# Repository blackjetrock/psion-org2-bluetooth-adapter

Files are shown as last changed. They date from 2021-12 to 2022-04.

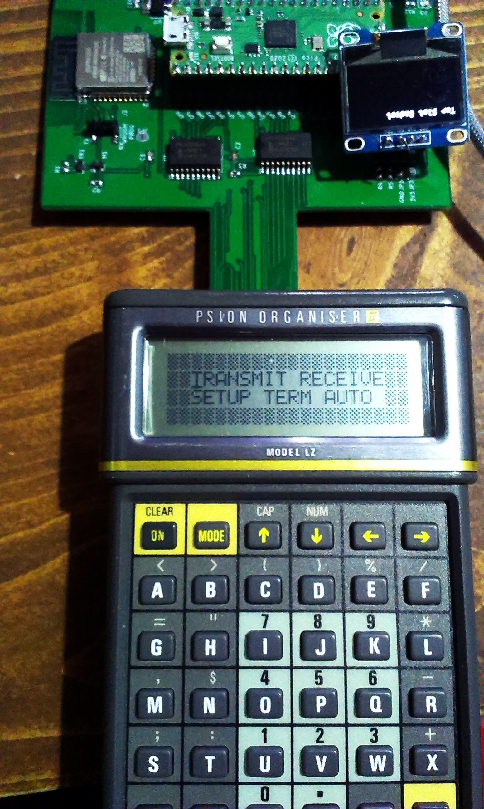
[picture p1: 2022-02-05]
photos/IMAG1584.jpg

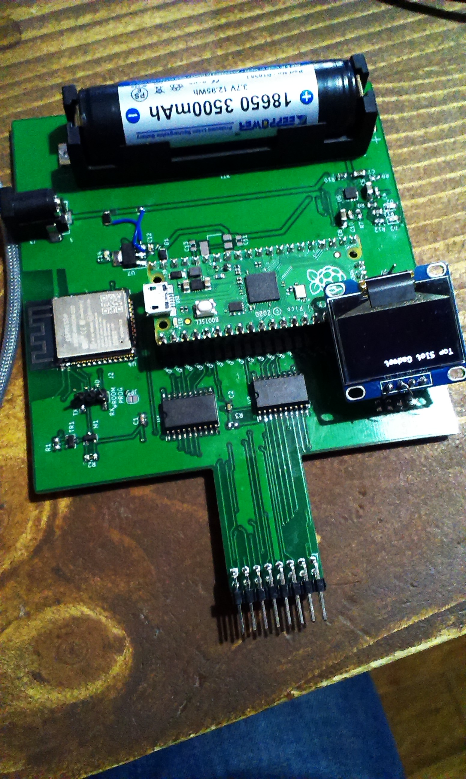
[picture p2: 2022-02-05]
photos/IMAG1581.jpg

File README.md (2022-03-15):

# psion-org2-bluetooth-adapter
Bluetooth adapter for Psion Organiser II

NOTE:Very much a prototype that needs modifications to run properly.

An adapter for the Psion Organiser II which has the Comms Link ROM in a Pico. hardware for bluetooth is a WROOM module.
The unit plugs in to the top slot of a PSion Organiser II and allows Bluetooth traffic to be passed on to the organiser.
The original comms link code runs on the Pico as it emulates a datapack ROM.

V1.0
----

Prototype PCB that is not designed to fit in a case.
Power from 1 cell Li-ion. Regulator should take input from jack and drop it to 5V. Battery charger/power path outputs 5.5V down to battery voltage. 
Pico takes output from regulator (5.5V to VBAT) and buck boosts to 3V3. 3V3 output from Pico drives external circuitry up to 300mA.
If running WROOM off 3V3 is too much then use 3V3 regulator off VREG.

V1.1
----

Movd charging circuit to the ETA6002 as soldering the BQxxx was tricky. This circuit doesn't really work as the datasheet has little data so I'm not sure about a lot of aspects of this chip. The code has had to be rewritten to not use interrupts. Instead of using one of the hardware UARTs and a PIO UART the code now uses two UARTS made fom PIOs. This doesn't use interrupts and works a lot better.
Master mode works on th elatest code and I have had two organisers communicating, on ein master mode and pone in slave using the TERM menu. Seems OK. The TRANSMIT menu option messes something up though, although it looks like the data is sent.
Turn off handshaking in the SETUP menu.
9600,n,8,1 is the Psion setting that is needed.

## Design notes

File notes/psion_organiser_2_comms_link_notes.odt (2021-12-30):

Psion organiser 2 Comms Link Notes

The 6303 has a serial IO capability on th efollowing pins:

Port2 Pin 3: Input (RX)

Port2 Pin 4: Output (TX)

The rate of transmission is set up in registers as required.

The 74HC244 places signals on the SDx bus when OE is asserted. If OE is not asserted then datapack Rom accesses can be made as normal.

OE on the 74HC244 is driven from the NAND of SOE and the inversion of SS.

So when SS is high and OE is high, the 74HC244 is enabled and pins 3 and 4 of the SDx bus are connected to the MAX232 driver.

The Rom is disabled at this time as SOE is high so there is no contention.

When the driver is not attached to the SD bus the RX and TX lineson the 25 way connector appear to be undefined. There are no pull ups or downs on the schematic.

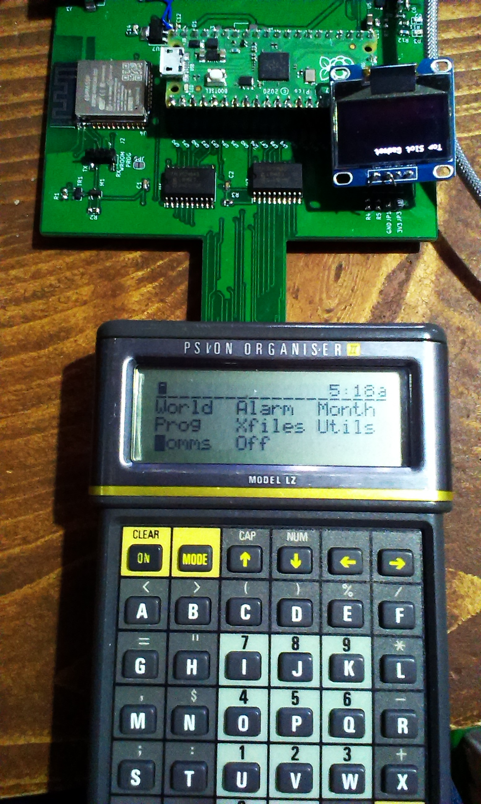
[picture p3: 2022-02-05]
photos/IMAG1583.jpg

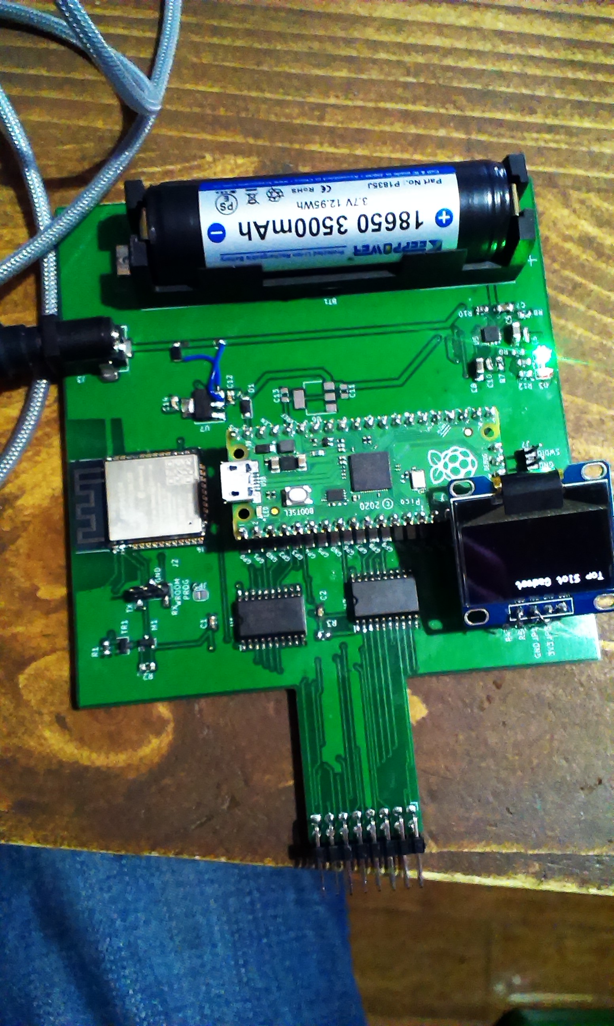
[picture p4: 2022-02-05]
photos/IMAG1582.jpg

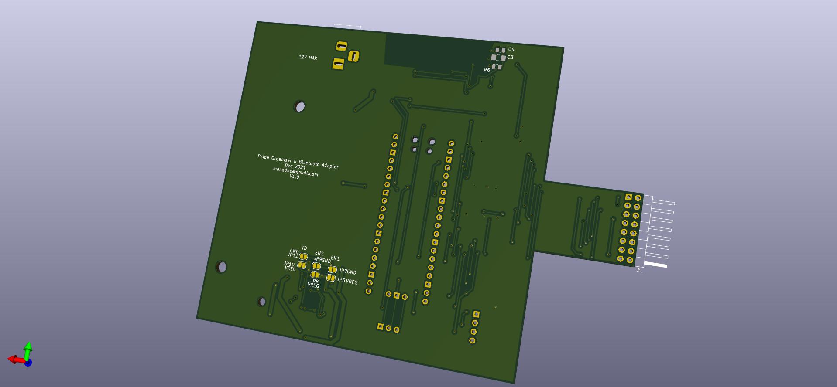
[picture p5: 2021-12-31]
pcbs/pcb_using_pico/psion-org2-bluetooth-adapter/fab1/psion-org2-bluetooth-adapter2.jpg

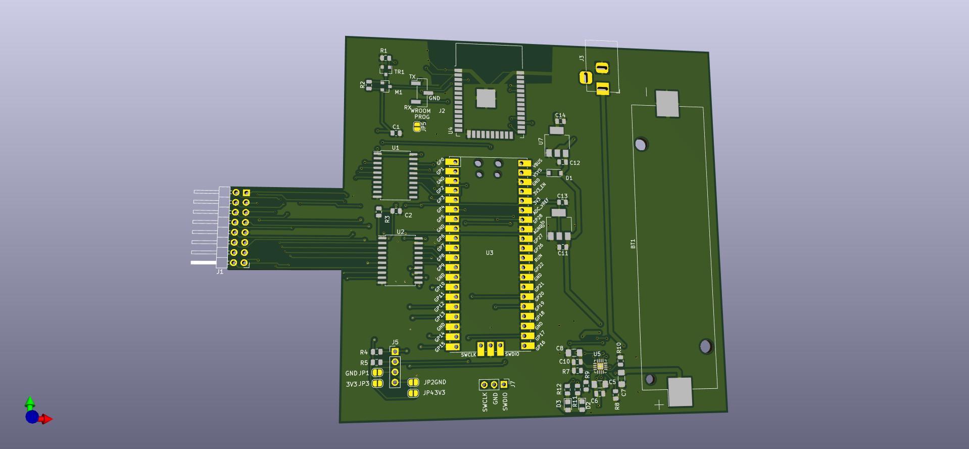
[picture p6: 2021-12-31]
pcbs/pcb_using_pico/psion-org2-bluetooth-adapter/fab1/psion-org2-bluetooth-adapter.jpg

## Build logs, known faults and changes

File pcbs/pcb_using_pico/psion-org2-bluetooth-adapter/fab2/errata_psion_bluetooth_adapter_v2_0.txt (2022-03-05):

Psion bluetooth Adapter V2.0 Errata
===================================

1. U8 pinout is wrong
2. LED on U8 should go to output of U8 not VREG as that can be powered by
   USB. Or not if USB not attached.

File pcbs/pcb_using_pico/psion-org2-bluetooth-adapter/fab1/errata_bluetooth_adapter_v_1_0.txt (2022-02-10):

Errata for Psion Organiser II Bluetooth Adapter
===============================================

1. Add a serial eeprom to store persistant info like BT IDs to connect to.
   Pico flash is fine, but may wear out faster than eeprom and be less
   replaceable  (more of a problem really).
2. Change supply so input goes to dc-dc converter to 6V or so then 5V
   regulator and then to battery charger IC. Charger IC has battery attached.
   Output from battery charger/power path goes to Pico which supplies 3V3
   using its buck-boost conbverter.
3. Allow 5V input from USB connector so power pack can be used as input
4. Swap to ETA6002 as the footprint is better for hand soldering.
5. Use a separate 3V3 regulator for the WROOM so we don't put that current
   through the 5V regulator and Pico.

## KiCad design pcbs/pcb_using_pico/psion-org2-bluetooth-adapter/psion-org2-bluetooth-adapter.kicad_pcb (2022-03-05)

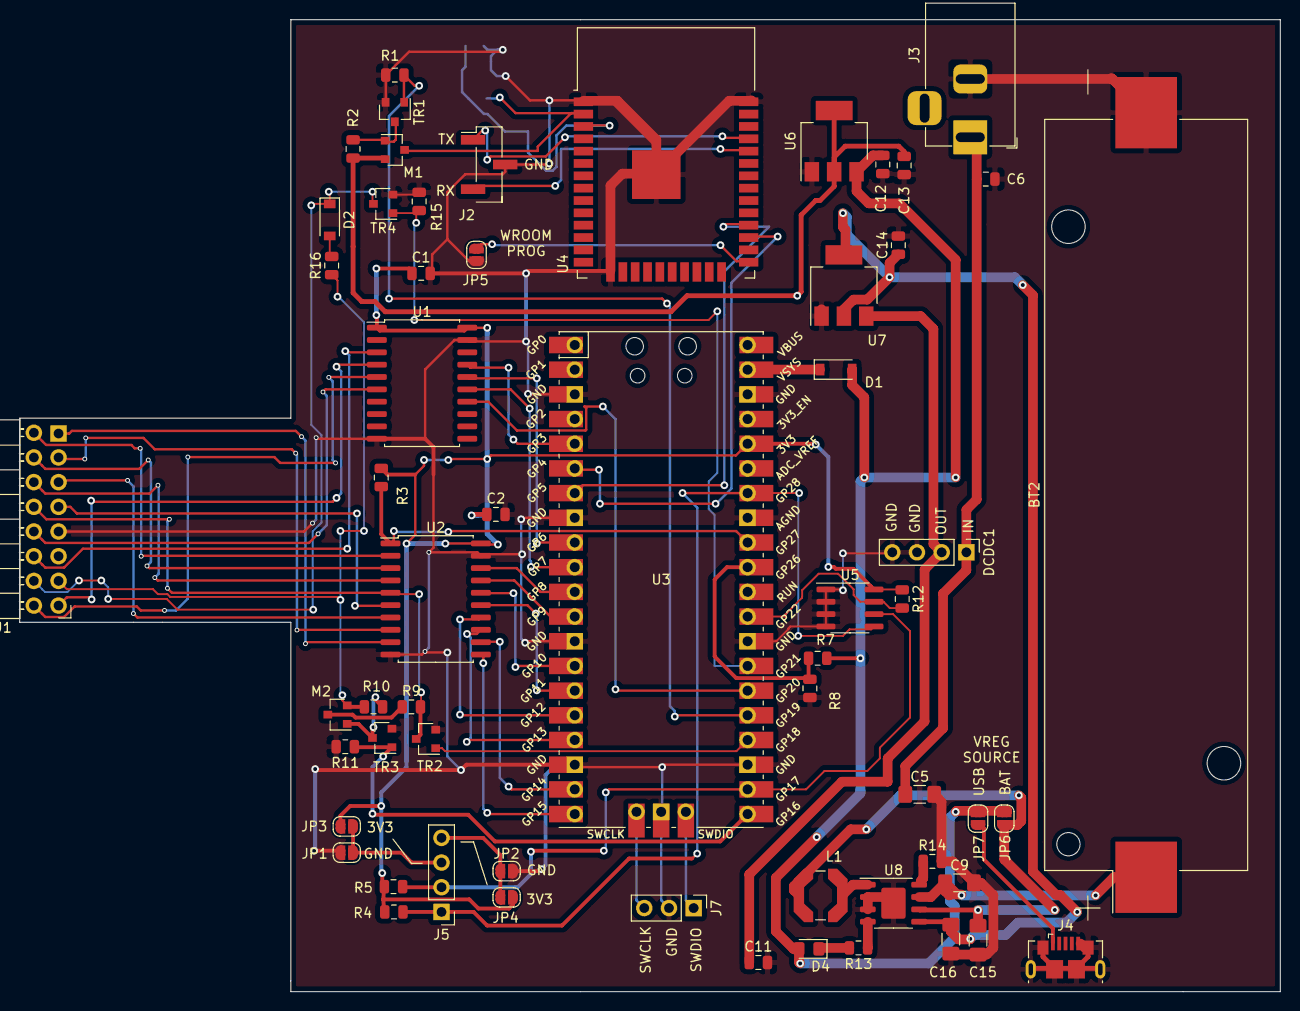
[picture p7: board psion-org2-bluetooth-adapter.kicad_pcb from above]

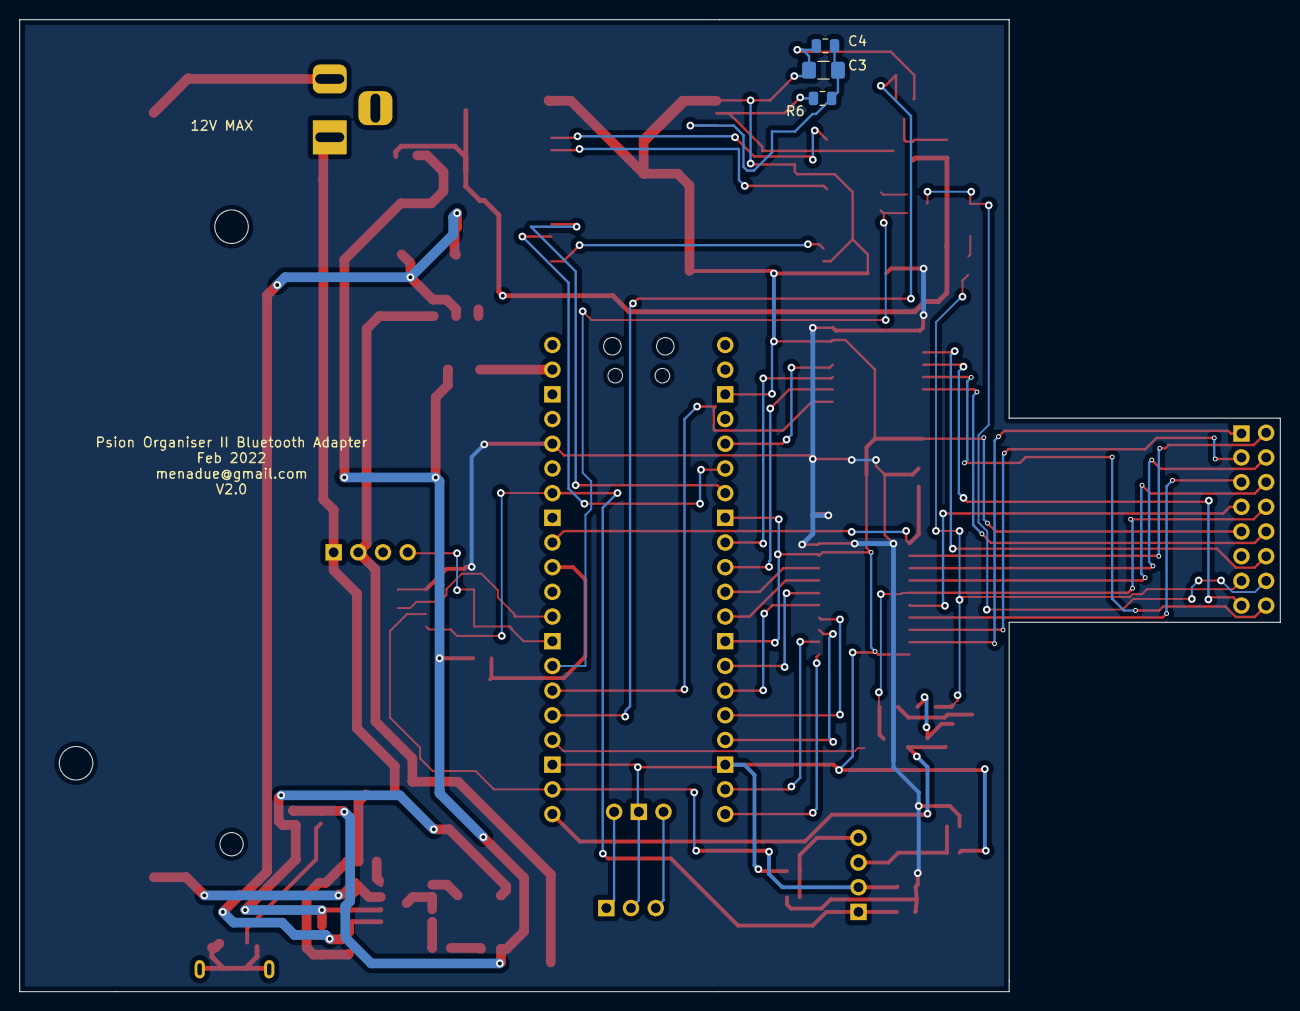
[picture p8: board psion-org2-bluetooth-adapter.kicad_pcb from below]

Board: 2 copper layers, 129.7 x 100.0 mm, 62 parts (3 on the bottom side), 65 nets.

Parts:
BT2: Battery_Cell; BatteryHolder_Keystone_1042_1x18650
C1, C2, C4, C6, C11, C12, C13, C14: 100nF; C_0805_2012Metric
C3: 4u7; C_1206_3216Metric_Pad1.42x1.75mm_HandSolder
C5, C16: 10uF; C_1206_3216Metric_Pad1.42x1.75mm_HandSolder
C9: 1uF; C_1206_3216Metric_Pad1.42x1.75mm_HandSolder
C15: 22uF; C_1206_3216Metric_Pad1.42x1.75mm_HandSolder
D1, D2: D_Schottky; D_SOD-123
D4: LED; LED_0805_2012Metric_Pad1.15x1.40mm_HandSolder
DCDC1: dcdc; PinHeader_1x04_P2.54mm_Vertical
J1: Conn_02x08_Odd_Even; Psion_datapak_2x08_P2.54mm_Horizontal
J2: Conn_01x03_Female; PinHeader_1x03_P2.54mm_Vertical_SMD_Pin1Left
J3: Barrel_Jack; BarrelJack_Horizontal
J4: Connector_USB_B_Micro; USB_Micro-B_GCT_USB3076-30-A
J5: Conn_01x04_Female; PinHeader_1x04_P2.54mm_Vertical
J7: Conn_01x03_Female; PinHeader_1x03_P2.54mm_Vertical
JP1, JP2, JP3, JP4, JP5, JP6, JP7: Jumper_NO_Small; SolderJumper-2_P1.3mm_Open_RoundedPad1.0x1.5mm
L1: 2.2uH; L_Coilcraft_LPS5030
M1: P-CHANNEL-MOSFET; SOT-23
M2: Si2301; SOT-23
R1, R2, R3, R6, R7, R8, R9, R12: R_Small; R_0805_2012Metric
R4, R5: 4k7; R_0805_2012Metric
R10, R11: 10k; R_0805_2012Metric
R13: 2k2; R_0805_2012Metric
R14: 500R; R_0805_2012Metric
R15, R16: 47k; R_0805_2012Metric
TR1, TR4: New_Library_Si2302CDS-n-channel; SOT-23
TR2: si2302; SOT-23
TR3: Si2302; SOT-23
U1, U2: 74LS245; SOIC-20W_7.5x12.8mm_P1.27mm
U3: Pico; RPi_Pico_SMD_TH
U4: ESP32-WROOM-32
U5: 24LC32; SOIC-8_3.9x4.9mm_P1.27mm
U6: AMS1117-3.3; SOT-223-3_TabPin2
U7: AMS1117-5.0; SOT-223-3_TabPin2
U8: ETA6002; SOIC-8-1EP_3.9x4.9mm_P1.27mm_EP2.514x3.2mm

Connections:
+3V3: C1.1, C2.1, JP3.2, JP4.2, R3.1, R4.1, R5.1, R12.1, U1.1, U1.20, U2.20, U3.36, U5.8
AC: D2.1, J1.14, TR4.3
AC_ON: R15.2, TR4.1, U3.27
EEPROM_WP: R12.2, U3.29, U5.7
ESP_3V3: C13.1, M1.2, R2.1, U6.2
GND: BT2.2, C1.2, C2.2, C3.2, C4.2, C5.2, C6.2, C9.2, C11.2, C12.2, C13.2, C14.2, C15.2, C16.2, DCDC1.3, DCDC1.4, J1.9, J2.2, J3.2, J4.5, J4.6, J7.2, JP1.2, JP2.2, JP5.2, R1.2, R8.2, R11.2, R14.2, R15.1, TR1.2, TR2.2, TR3.2, TR4.2, U1.10, U1.19, U2.10, U2.19, U3.3, U3.8, U3.13, U3.18, U3.23, U3.28, U3.33, U3.38, U3.42, U4.1, U4.15, U4.38, U4.39, U5.1, U5.2, U5.3, U5.4, U6.1, U7.1, U8.2, U8.3, U8.9
I2C_SCLK: J5.2, R5.2, U3.22, U5.6
I2C_SDA: J5.1, R4.2, U3.34, U5.5
LS_DIR: R3.2, U2.1, U3.32
unnamed: BT2.1, C9.1, U8.6
unnamed: C3.1, C4.1, R6.2, U4.3
unnamed: C5.1, C6.1, DCDC1.1, J3.1
unnamed: C11.1, DCDC1.2, U7.3
unnamed: C14.1, C16.1, U7.2, U8.8
unnamed: C15.1, JP6.2, L1.2, U8.7
unnamed: D1.1, U3.39
unnamed: D2.2, R16.2
unnamed: D4.1, R13.2
unnamed: J2.1, U4.35
unnamed: J2.3, U4.34
unnamed: J4.1, JP7.2
unnamed: J5.3, JP1.1, JP3.1
unnamed: J5.4, JP2.1, JP4.1
unnamed: J7.1, U3.43
unnamed: J7.3, U3.41
unnamed: JP5.1, U4.25
unnamed: L1.1, U8.1
unnamed: M1.1, R2.2, TR1.3
unnamed: M2.1, R10.2, TR3.3
unnamed: M2.3, R9.1
unnamed: R7.2, R8.1, U3.31
unnamed: R13.1, U8.4
unnamed: R14.1, U8.5
PICO_RX: U3.7, U4.28
PICO_TX: U3.6, U4.27
P_SCLK: U1.14, U3.26
P_SD0: U2.18, U3.11
P_SD1: U2.17, U3.12
P_SD2: U2.16, U3.14
P_SD3: U2.15, U3.15
P_SD4: U2.14, U3.16
P_SD5: U2.13, U3.17
P_SD6: U2.12, U3.19
P_SD7: U2.11, U3.20
P_SMR: U1.15, U3.10
P_SOE: U1.16, U3.9
P_SS: U1.17, U3.5
SCLK: J1.10, U1.6
SD0: J1.2, U2.2
SD1: J1.4, U2.3
SD2: J1.6, U2.4
SD3: J1.8, R9.2, TR2.3, U2.5
SD4: J1.7, U2.6
SD5: J1.5, U2.7
SD6: J1.3, U2.8
SD7: J1.1, U2.9
SMR: J1.16, U1.5
SOE: J1.15, U1.4
SS: J1.12, U1.3
TRI_TX: R11.1, TR3.1, U3.21
TX_TO_PSION: TR2.1, U3.24
VCC: J1.13, M2.2, R10.1, R16.1
VCC_ESP: M1.3, R6.1, U4.2
VREG: C12.1, D1.2, D4.2, JP6.1, JP7.1, R7.1, U6.3
WROOM_ON: R1.1, TR1.1, U3.25

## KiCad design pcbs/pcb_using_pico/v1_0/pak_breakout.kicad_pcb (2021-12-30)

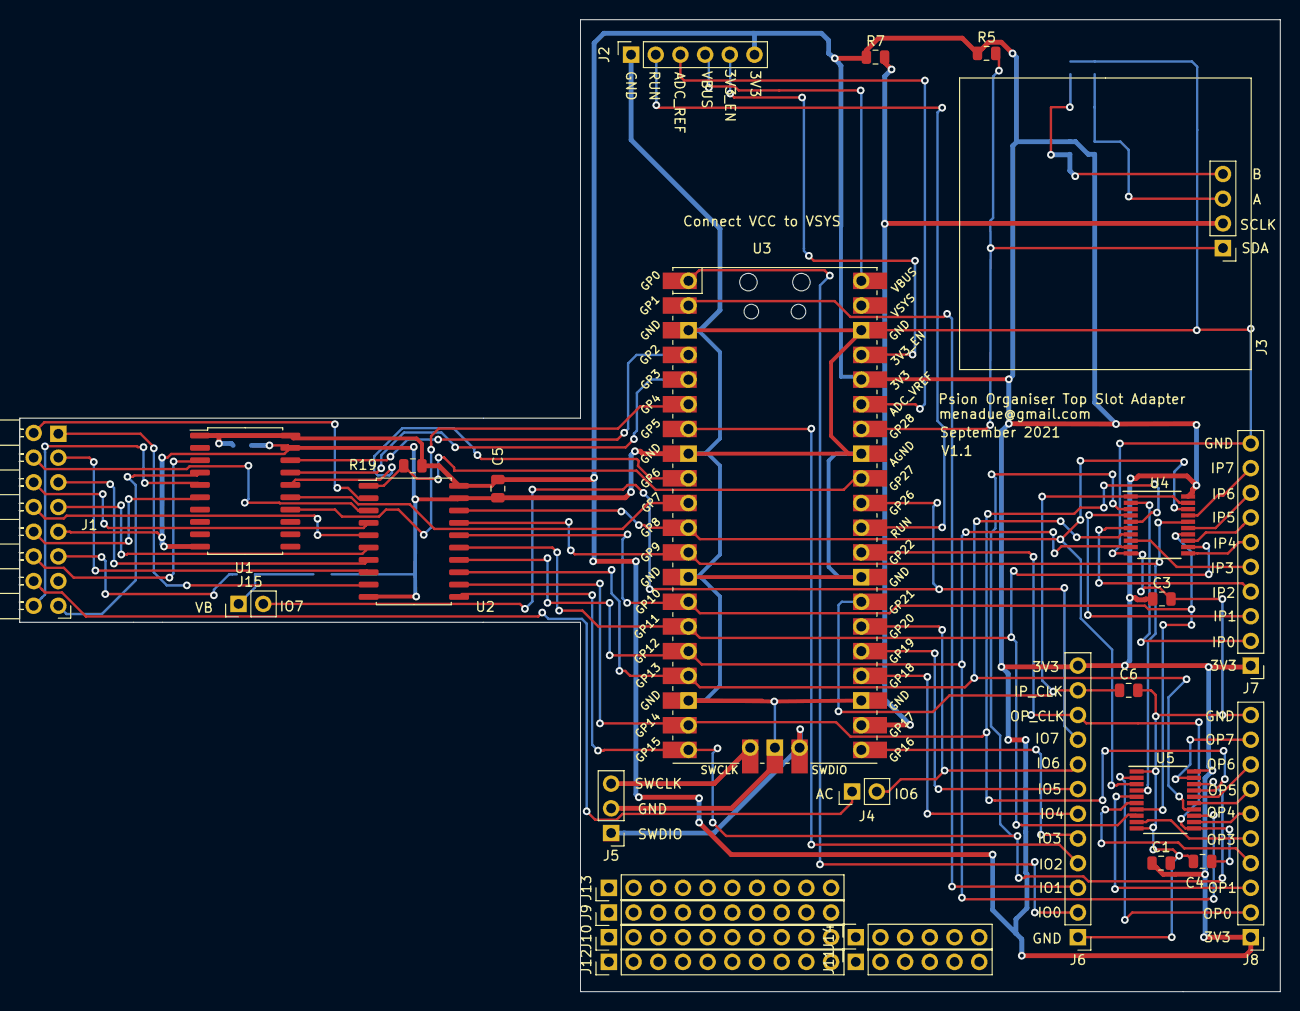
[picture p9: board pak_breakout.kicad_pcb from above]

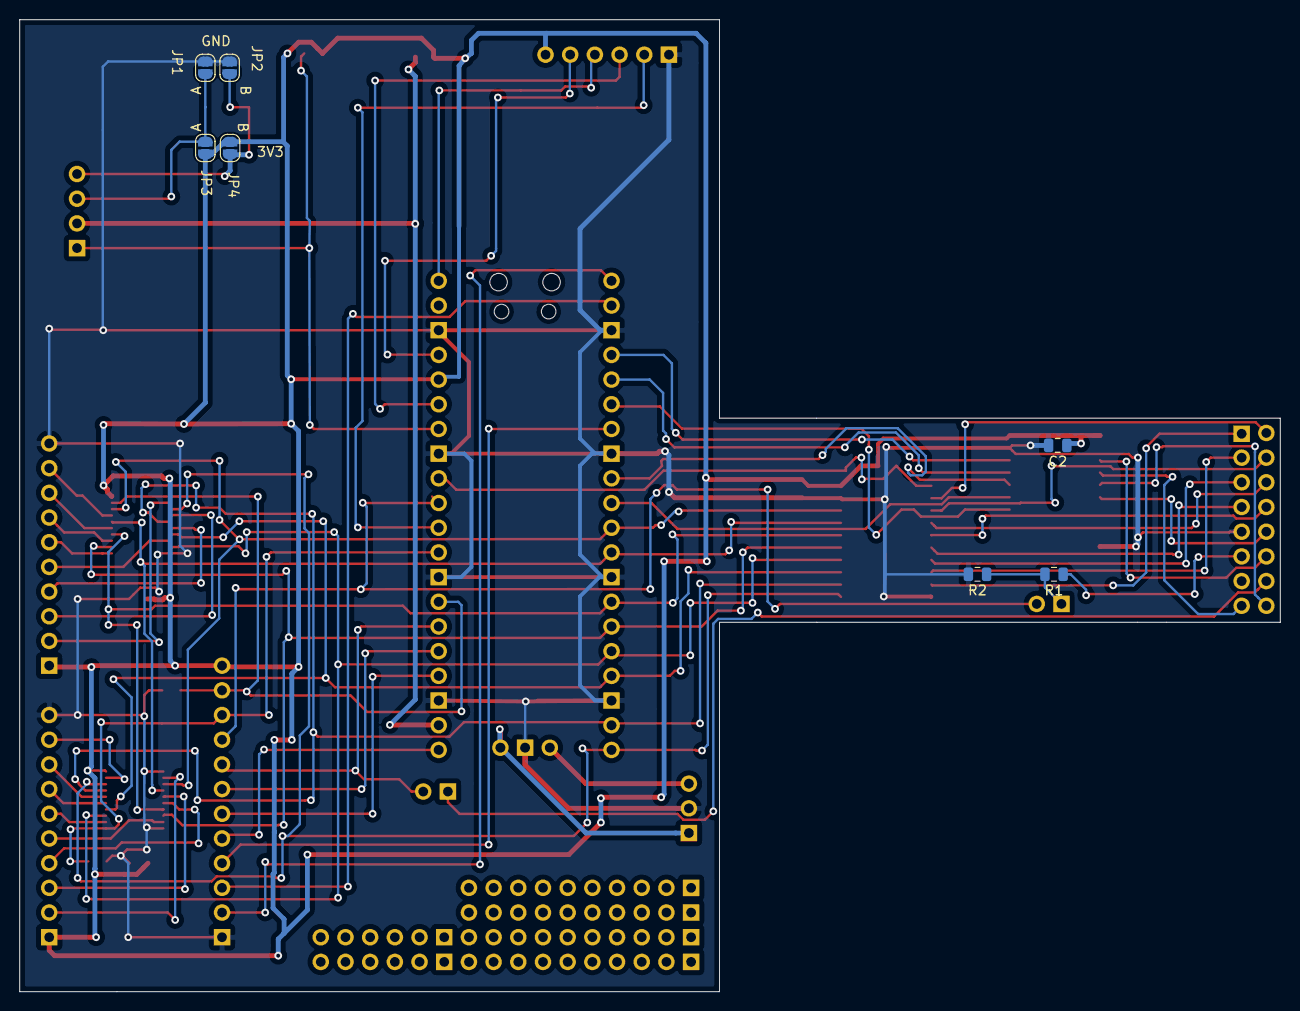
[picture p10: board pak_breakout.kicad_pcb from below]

Board: 2 copper layers, 129.7 x 100.0 mm, 35 parts (7 on the bottom side), 67 nets.

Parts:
C1, C3: C_Small; C_0805_2012Metric
C2, C5: 100nF; C_0805_2012Metric
C4, C6: 33pF; C_0805_2012Metric
J1: Conn_02x08_Odd_Even; Psion_datapak_2x08_P2.54mm_Horizontal
J2, J11, J14: Conn_01x06_Female; PinSocket_1x06_P2.54mm_Vertical
J3: Conn_01x04_Female; PinHeader_1x04_P2.54mm_Vertical
J4, J15: Conn_01x02_Male; PinHeader_1x02_P2.54mm_Vertical
J5: Conn_01x03_Female; PinHeader_1x03_P2.54mm_Vertical
J6: Conn_01x12_Female; PinHeader_1x12_P2.54mm_Vertical
J7, J8, J9, J10, J12, J13: Conn_01x10_Female; PinHeader_1x10_P2.54mm_Vertical
JP1, JP2, JP3, JP4: Jumper_NO_Small; SolderJumper-2_P1.3mm_Open_RoundedPad1.0x1.5mm
R1, R2, R19: R_Small; R_0805_2012Metric
R5, R7: 4k7; R_0805_2012Metric
U1, U2: 74LS245; SOIC-20W_7.5x12.8mm_P1.27mm
U3: Pico; RPi_Pico_SMD_TH
U4: 74LS244; TSSOP-20_4.4x6.5mm_P0.65mm
U5: 74LS374; TSSOP-20_4.4x6.5mm_P0.65mm

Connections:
3V3_EN: J2.5, U3.37
+3V3: C1.1, C2.1, C3.1, C5.1, J2.6, J6.12, J7.1, J8.1, JP3.2, JP4.2, R5.1, R7.1, R19.1, U1.1, U1.20, U2.20, U3.36, U4.20, U5.20
AC: J1.14, J4.1
ADC_REF: J2.3, U3.35
GND: C1.2, C2.2, C3.2, C4.2, C5.2, C6.2, J1.9, J2.1, J5.2, J6.1, J7.10, J8.10, JP1.2, JP2.2, R2.2, U1.10, U1.19, U2.10, U2.19, U3.3, U3.8, U3.13, U3.18, U3.23, U3.28, U3.33, U3.38, U3.42, U4.10, U5.1, U5.10
I2C_SCLK: J3.2, R7.2, U3.22
I2C_SDA: J3.1, R5.2, U3.34
IO0: J6.2, U3.1
IO1: J6.3, U3.2
IO2: J6.4, U3.7
IO3: J6.5, U3.21
IO4: J6.6, U3.24
IO5: J6.7, U3.25
IO6: J4.2, J6.8, U3.26
IO7: J6.9, J15.2, U3.31
IP0: J7.2, U4.2
IP1: J7.3, U4.4
IP2: J7.4, U4.6
IP3: J7.5, U4.8
IP4: J7.6, U4.11
IP5: J7.7, U4.13
IP6: J7.8, U4.15
IP7: J7.9, U4.17
IP_CLK: C6.1, J6.11, U3.27, U4.1, U4.19
LS_DIR: R19.2, U2.1, U3.32
unnamed: J3.3, JP1.1, JP3.1
unnamed: J3.4, JP2.1, JP4.1
unnamed: J5.1, U3.43
unnamed: J5.3, U3.41
unnamed: J15.1, R1.2, R2.1
OP0: J8.2, U5.2
OP1: J8.3, U5.5
OP2: J8.4, U5.6
OP3: J8.5, U5.9
OP4: J8.6, U5.12
OP5: J8.7, U5.15
OP6: J8.8, U5.16
OP7: J8.9, U5.19
OP_CLK: C4.1, J6.10, U3.29, U5.11
P_SCLK: U1.14, U3.6
P_SD0: U2.18, U3.11, U4.18, U5.3
P_SD1: U2.17, U3.12, U4.16, U5.4
P_SD2: U2.16, U3.14, U4.14, U5.7
P_SD3: U2.15, U3.15, U4.12, U5.8
P_SD4: U2.14, U3.16, U4.9, U5.13
P_SD5: U2.13, U3.17, U4.7, U5.14
P_SD6: U2.12, U3.19, U4.5, U5.17
P_SD7: U2.11, U3.20, U4.3, U5.18
P_SMR: U1.15, U3.10
P_SOE: U1.16, U3.9
P_SPGM: U1.18, U3.4
P_SS: U1.17, U3.5
RUN: J2.2, U3.30
SCLK: J1.10, U1.6
SD0: J1.2, U2.2
SD1: J1.4, U2.3
SD2: J1.6, U2.4
SD3: J1.8, U2.5
SD4: J1.7, U2.6
SD5: J1.5, U2.7
SD6: J1.3, U2.8
SD7: J1.1, U2.9
SMR: J1.16, U1.5
SOE: J1.15, U1.4
SS: J1.12, U1.3
VB: J1.11, R1.1
VBUS: J2.4, U3.40

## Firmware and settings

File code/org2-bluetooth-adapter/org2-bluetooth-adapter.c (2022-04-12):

////////////////////////////////////////////////////////////////////////////////
//
// Psion Organiser II Top Slot Breakout
//
////////////////////////////////////////////////////////////////////////////////

#include <ctype.h>
#include <stdio.h>
#include <string.h>
#include <stdlib.h>
#include "pico/stdlib.h"
//#include "hardware/i2c.h"
//#include "hardware/pio.h"
//#include "hardware/clocks.h"
#include "pico/multicore.h"

//#include "f_util.h"

//#include "ff.h"
//#include "ff_stdio.h"
//#include "hw_config.h"
//#include "my_debug.h"
//#include "rtc.h"
//#include "sd_card.h"

// Use this if breakpoints don't work
#define DEBUG_STOP {volatile int x = 1; while(x) {} }

// Are we compiling for the gadget breakout or the picopak?
#define PICOPAK 0

// Bluetooth adapter pinout slightly different
#define BLUETOOTH_ADAPTER 1

// Drop into a loop that displays key states and does nothing else
#define KEY_DEBUG_ONLY                0
#define TEST_IOPORT                   0

// Interrupts may muck up the pack interface, but it does seem to run with them enabled.
// If USB is ever to work then interrupts need to be enabled.
#define NO_INTERRUPTS_WHILE_POLLING   1
#define TEST_STDIO                    0

// Redefine pins to match our hardware
#define PICO_SD_CLK_PIN        5
#define PICO_SD_CMD_PIN       18
#define PICO_SD_DAT0_PIN      19
#define ENABLE_4_PIN           0

#define SUPPORT_ID_BYTE        1
#define PAK_ID_BYTE         0x01
#define READ_ONLY              0
#define INIT_PAK_MEMORY        1
#define FF_FIRST_BYTES         0

// Direct access to GPIO registers is faster, and we need speed
#define DIRECT_GPIO            1

// Number of buttons used for the menu system. The 'exit polling' button is not in this
// list, it is coded as a GPIO line as we don't want to waste time processing the menu
// buttons inthe fast polling loop

#define NUM_BUTTONS            3

// All organiser files are in this subdirectory on the SD card, just to keep things tidy
// and allow the card to be used for other things if needed.
#define PAK_DIR                "/PAK"

// Debounce
#define MAX_BUT_COUNT          6

bool sd_ok_flag = false;

// Do we use a polling loop of interrupts?
#define USE_INTERRUPTS         0
#define USE_POLLING            1

// For added speed, we poll the address counter stuff on the other core
#define MULTICORE_POLL         1

// The address into pak memory
#define PAK_ADDRESS (ss_address | ss_page)

// For the OLED display
const uint SDA_PIN             = 28;
const uint SCL_PIN             = 17;

#ifndef I2C_FUNCTIONS_H_
#define I2C_FUNCTIONS_H_

typedef unsigned char BYTE;

const int IO0_PIN       = 0;
const int IO1_PIN       = 1;
const int IO2_PIN       = 5;
const int IO3_PIN       = 16;
const int IO4_PIN       = 18;
const int IO5_PIN       = 19;
const int IO6_PIN       = 20;

const int OP_CLK_PIN    = 22;
const int IP_CLK_PIN    = 21;

// IO7 can also be used to measure battery voltage
const int IO7_PIN       = 26;

const int SLOT_SPGM_PIN = 2;
const int SLOT_SS_PIN   = 3;

#if BLUETOOTH_ADAPTER
const int SLOT_SCLK_PIN = 20;
#else
const int SLOT_SCLK_PIN = 4;
#endif

const int SLOT_SOE_PIN  = 6;
const int SLOT_SMR_PIN  = 7;

const int SLOT_SD0_PIN  = 8;
const int SLOT_SD1_PIN  = 9;
const int SLOT_SD2_PIN  = 10;
const int SLOT_SD3_PIN  = 11;
const int SLOT_SD4_PIN  = 12;
const int SLOT_SD5_PIN  = 13;
const int SLOT_SD6_PIN  = 14;
const int SLOT_SD7_PIN  = 15;

const int LS_DIR_PIN    = 27;

volatile int ss_count = 0;
volatile int soe_state = 1;
volatile int ss_address = 0;
volatile int ss_page = 0;


// Memory that emulates a pak
typedef unsigned char BYTE;
typedef void (*FPTR)();
typedef void (*CMD_FPTR)(char *cmd);

// The tracing was used for low level analysis of the protocol
#define TRACE_LENGTH 8192
BYTE trace[TRACE_LENGTH];

int trace_i = 0;
#define TRACE(XX) if(trace_i != (TRACE_LENGTH-1)) {trace[trace_i++] = XX; trace_i %= TRACE_LENGTH;}
//#define TRACE(XX)

//#define WRITE_TRAP if( (PAK_ADDRESS + data) == 0)  while(1);

#define WRITE_TRAP

#define PAK_MEMORY_SIZE  65536
//#define PAK_MEMORY_SIZE  32768

// Allow a file to be selected. The file name will be stored for a later 'read' command.

int file_offset = 0;
int max_filenum = 0;

// File names for paks that are written to SD card
#define FILE_PAGE 7
#define PAK_FILE_NAME_FORMAT "pak%05d.opk"
#define PAK_FILE_NAME_GLOB   "pak*.opk"

// I2C Port descriptor
typedef struct _I2C_PORT_DESC
{
  unsigned char sdaport;
  unsigned char sdabit;
  unsigned char sclport;
  unsigned char sclbit;
} I2C_PORT_DESC;


// Slave device descriptor
typedef struct _I2C_SLAVE_DESC
{
  I2C_PORT_DESC *port;             // Port the device is on
  unsigned char slave_7bit_addr;        // SLave address
} I2C_SLAVE_DESC;


#if PICOPAK
#define MENU_MAX  3
#else
#define MENU_MAX  6
#endif

int menu_offset = 0;

typedef struct _BUTTON
{
  int     count;
  bool pressed;
  bool last_pressed;   // For edge detection
  FPTR    event_fn;
} BUTTON;

BUTTON buttons[NUM_BUTTONS];
enum ELEMENT_TYPE
  {
   BUTTON_ELEMENT = 10,
   SUB_MENU,
   MENU_END,
  };

struct MENU_ELEMENT
{
  enum ELEMENT_TYPE type;
  char *text;
  void *submenu;
  void (*function)(struct MENU_ELEMENT *e);
};

void button_display(struct MENU_ELEMENT *e);
void button_list(struct MENU_ELEMENT *e);
//void but_ev_file_up();
//void but_ev_file_down();
void but_ev_file_select();

void loop_delay(int delay)
{
  volatile x, y;

  for(x=0; x<delay; x++)
    {
      for(y=0; y<10; y++)
	{
	}
    }
}

int menuloop_done = 0;

#if !INIT_PAK_MEMORY
volatile BYTE pak_memory[PAK_MEMORY_SIZE];
#else

volatile BYTE pak_memory_assem[] =
  {
   // ASSEMBLER_EMBEDDED_CODE_START
0x46,0x04,0x01,0x0A,0x00,0x0A,0x00,0x19,0xFF,0xFF,0x09,0x81,0x4D,0x41,0x49,0x4E,
0x20,0x20,0x20,0x20,0x90,0x02,0x80,0x03,0xB1,0x03,0x55,0x00,0x00,0x00,0x0A,0x00,
0x03,0x00,0x62,0x00,0xA4,0x00,0xCE,0x08,0x4C,0x41,0x54,0x4F,0x55,0x54,0x41,0x41,
0x01,0xA7,0x08,0x4C,0x41,0x54,0x4F,0x55,0x54,0x30,0x30,0x01,0xAE,0x08,0x4C,0x41,
0x54,0x4F,0x55,0x54,0x46,0x46,0x01,0xB5,0x05,0x4C,0x41,0x54,0x49,0x4E,0x01,0x45,
0x09,0x50,0x49,0x43,0x4F,0x4F,0x55,0x54,0x41,0x41,0x01,0x05,0x09,0x50,0x49,0x43,
0x4F,0x4F,0x55,0x54,0x30,0x30,0x01,0x64,0x09,0x50,0x49,0x43,0x4F,0x4F,0x55,0x54,
0x46,0x46,0x01,0x6B,0x06,0x50,0x49,0x43,0x4F,0x49,0x4E,0x01,0x64,0xCE,0x00,0x0C,
0xBD,0x00,0x93,0xCE,0x00,0x17,0xBD,0x00,0x93,0xCE,0x00,0x22,0xBD,0x00,0x93,0xCE,
0x00,0x2D,0xBD,0x00,0x93,0xCE,0x00,0x35,0xBD,0x00,0x93,0xCE,0x00,0x41,0xBD,0x00,
0x93,0xCE,0x00,0x4D,0xBD,0x00,0x93,0xCE,0x00,0x59,0xBD,0x00,0x93,0x39,0xE6,0x00,
0xCB,0x03,0x4F,0xDD,0x41,0xCC,0x21,0x87,0x3F,0x6D,0xC6,0xFF,0x3F,0x65,0x39,0xCE,
0x00,0x0C,0x3F,0x67,0xCE,0x00,0x17,0x3F,0x67,0xCE,0x00,0x22,0x3F,0x67,0xCE,0x00,
0x2D,0x3F,0x67,0xCE,0x00,0x35,0x3F,0x67,0xCE,0x00,0x41,0x3F,0x67,0xCE,0x00,0x4D,
0x3F,0x67,0xCE,0x00,0x59,0x3F,0x67,0x0C,0x39,0x0D,0x39,0x36,0x4F,0xC6,0x03,0x3F,
0x62,0x72,0x40,0x17,0x86,0xFF,0x97,0x01,0x32,0x97,0x03,0x72,0x08,0x17,0x71,0xFD,
0x17,0x71,0xBF,0x17,0x71,0xBF,0x17,0x71,0xBF,0x17,0x71,0xBF,0x17,0x72,0x40,0x17,
0x72,0x40,0x17,0x72,0x40,0x17,0x7F,0x00,0x01,0x71,0xF7,0x17,0x72,0x40,0x17,0x39,
0x86,0xAA,0xBD,0x00,0xD0,0x0C,0x39,0x4F,0xC6,0x03,0x3F,0x62,0x72,0x40,0x17,0x86,
0xFF,0x7F,0x00,0x01,0x71,0xF7,0x17,0x72,0x02,0x17,0x71,0xFE,0x17,0x71,0xBF,0x17,
0x71,0xBF,0x17,0x71,0xBF,0x17,0x71,0xBF,0x17,0x96,0x03,0x36,0x72,0x40,0x17,0x72,
0x40,0x17,0x72,0x40,0x17,0x7F,0x00,0x01,0x71,0xF7,0x17,0x72,0x40,0x17,0x32,0x39,
0xCE,0x00,0x00,0x3F,0x14,0x86,0xAA,0xBD,0x01,0x0C,0x36,0x3F,0x6F,0x0C,0x49,0x4C,
0x41,0x54,0x3A,0x25,0x79,0x00,0x3F,0x4B,0x5D,0x27,0xE5,0x3F,0x48,0x0C,0x39,0x86,
0x00,0xBD,0x00,0xD0,0x0C,0x39,0x86,0xFF,0xBD,0x00,0xD0,0x0C,0x39,0x36,0x4F,0xC6,
0x03,0x3F,0x62,0x72,0x40,0x17,0x86,0xFF,0x97,0x01,0x32,0x97,0x03,0x72,0x08,0x17,
0x72,0x02,0x17,0x72,0x01,0x17,0x71,0xBF,0x17,0x71,0xBF,0x17,0x71,0xBF,0x17,0x72,
0x40,0x17,0x72,0x40,0x17,0x72,0x40,0x17,0x7F,0x00,0x01,0x71,0xF7,0x17,0x72,0x40,
0x17,0x39,0x86,0xAA,0xBD,0x01,0x72,0x0C,0x39,0x86,0x00,0xBD,0x01,0x72,0x0C,0x39,
0x86,0xFF,0xBD,0x01,0x72,0x0C,0x39,0x00,0x00,0x00,0x00,0x00,0x00,0x00,0x00,0x00,
0x00,0x00,0x00,0x00,0x00,0x00,0x00,0x00,0x00,0x00,0x00,0x00,0x00,0x00,0x00,0x00,
0x00,0x00,0x00,0x00,0x00,0x00,0x00,0x00,0x00,0x00,0x00,0x00,0x00,0x00,0x00,0x00,
0x00,0x00,0x00,0x00,0x00,0x00,0x00,0x00,0x00,0x00,0x00,0x00,0x00,0x00,0x00,0x00,
0x00,0x00,0x00,0x00,0x00,0x00,0x00,0x00,0x00,0x00,0x00,0x00,0x00,0x00,0x00,0x00,
0x00,0x00,0x00,0x00,0x00,0x00,0x00,0x00,0x0F,0x00,0x00,0x00,0x00,0x00,0x00,0x00,
0x00,0x00,0x00,0x00,0x00,0x00,0x00,0x00,0x00,0x00,0x00,0x00,0x00,0x00,0x00,0x00,
0x00,0x00,0x00,0x00,0x00,0x00,0x00,0x00,0x00,0x00,0x00,0x00,0x00,0x00,0x00,0x00,
0x00,0x00,0x00,0x00,0x00,0x00,0x00,0x00,0x00,0x00,0x00,0x00,0x00,0x00,0x00,0x00,
0x00,0x00,0x00,0x00,0x00,0x00,0x00,0x00,0x00,0x00,0x00,0x00,0x00,0x00,0x00,0x00,
0x00,0x00,0x00,0x00,0x00,0x00,0x00,0x00,0x00,0x00,0x00,0x00,0x00,0x00,0x00,0x00,
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
// ASSEMBLER_EMBEDDED_CODE_END
  };

// Pre-initialised pack memory.
// This is a copy of the V2.5 Comms link ROM, just as a test of the board.
// For proper applications this will contain whatever code is needed to drive the
// hardware.

volatile BYTE pak_memory[] =
  {
   0x6a,0x04,0x01,0xc0,0x25,0xc0,0x00,0x19,0xff,0xff,
   0x09,0x81,0x4d,0x41,0x49,0x4e,0x20,0x20,0x20,0x20,0x90,0x02,0x80,0x57,0xcd,0x10,
   0x39,0x00,0x00,0x00,0xc0,0x25,0x14,  0x06,0x4b,0x01,0xa7,0x01,0xc5,0x06,0x70,0x06,
   0x7a,0x06,0xa8,0x06,0xad,0x06,0xa3,0x06,0x85,0x06,0x8a,0x06,0x8f,0x06,0x62,0x06,
   0x9e,0x06,0xbe,0x06,0x94,0x06,0xfc,0x06,0xf7,0x06,0xb2,0x06,0x75,0x06,0x99,0xff,
   0xff,0xff,0xff,0xff,0xff,0xff,0xff,0xff,0xff,0xff,0xff,0xff,0xff,0xff,0xff,0xff,
   0xff,0xff,0xff,0xff,0xff,0xff,0xff,0xff,0xff,0xff,0xff,0xff,0xff,0xff,0xff,0xff,
   0xff,0xff,0xff,0xff,0xff,0xff,0xff,0xff,0xff,0xff,0xff,0xff,0xff,0xff,0xff,0xff,
   0xff,0xff,0xff,0xff,0xff,0xff,0xff,0xff,0xff,0xff,0xff,0xff,0xff,0xff,0xff,0xff,
   0xff,0xff,0xff,0xff,0xff,0xff,0xff,0xff,0xff,0xff,0xff,0xff,0xff,0xff,0xff,0xff,
   0xff,0xff,0xff,0xff,0xff,0xff,0xff,0xff,0xff,0xff,0xff,0xff,0xff,0xff,0xff,0xff,
   0xff,0xff,0xff,0xff,0xff,0xff,0xff,0xff,0xff,0xff,0xff,0xff,0xff,0xff,0xff,0xff,
   0xff,0xff,0xff,0xff,0xff,0xff,0xff,0xff,0xff,0xff,0xff,0xff,0xff,0xff,0xff,0xff,
   0x00,0x00,0x00,0x00,0x34,0x00,0x00,0x00,0x00,0x00,0x00,0xff,0x00,0xff,0xff,0xff,
   0xff,0xff,0xff,0xff,0xff,0xff,0xff,0xc7,0xaf,0xa0,0x97,0x5f,0x2f,0x17,0x0b,0x05,
   0x02,0xff,0xff,0xff,0xff,0x02,0xff,0xff,0xff,0xff,0xff,0xff,0xff,0xff,0xff,0xff,
   0xff,0xff,0xff,0xff,0xff,0xff,0x00,0xff,0xff,0xff,0xff,0x05,0x43,0x4f,0x4d,0x4d,
   0x53,0x07,0x2b,0x02,0x07,0xff,0x02,0xbd,0xff,0x04,0x82,0xff,0x04,0xef,0xff,0x02,
   0x03,0xff,0x05,0xe9,0xff,0x08,0xb6,0x04,0x09,0x8d,0x04,0x0b,0xc3,0x10,0x0b,0xd3,
   0x10,0x0c,0x01,0x10,0x0c,0x29,0x10,0x04,0x4c,0x53,0x45,0x54,0x05,0x54,0x52,0x49,
   0x47,0x24,0x05,0x58,0x46,0x45,0x4f,0x46,0x05,0x58,0x46,0x50,0x4f,0x53,0x05,0x58,
   0x46,0x50,0x55,0x54,0x05,0x58,0x4c,0x43,0x4f,0x4e,0x05,0x58,0x4c,0x44,0x49,0x53,
   0x05,0x58,0x4c,0x50,0x55,0x54,0x06,0x4c,0x50,0x52,0x49,0x4e,0x54,0x06,0x58,0x46,
   0x47,0x45,0x54,0x24,0x06,0x58,0x46,0x4f,0x50,0x45,0x4e,0x06,0x58,0x4c,0x47,0x45,
   0x54,0x24,0x06,0x58,0x4d,0x4c,0x4f,0x41,0x44,0x06,0x58,0x54,0x52,0x45,0x43,0x56,
   0x06,0x58,0x54,0x53,0x45,0x4e,0x44,0x07,0x4c,0x49,0x4e,0x50,0x55,0x54,0x24,0x07,
   0x58,0x46,0x43,0x4c,0x4f,0x53,0x45,0x00,0x07,0x4b,0x11,0x78,0x07,0x4b,0x12,0x15,
   0x07,0x4b,0x16,0xc1,0x07,0x4b,0x1f,0x3c,0x07,0x4b,0x24,0xb5,0x07,0x4b,0x3d,0xd2,
   0x07,0x4b,0x3e,0x86,0x07,0x4b,0x54,0xc9,0xde,0x47,0x3c,0xde,0x4b,0x3c,0xc6,0x01,
   0xbd,0x02,0xbd,0xce,0x00,0xea,0x3f,0x67,0xfc,0x00,0xb8,0xf7,0x21,0x72,0x38,0xdf,
   0x4b,0x38,0xdf,0x47,0x0c,0x39,0xdf,0xe4,0xce,0x01,0x16,0xdf,0xea,0x86,0x02,0x97,
   0xe8,0x7c,0x00,0xe8,0xde,0xea,0xdf,0xe6,0xa6,0x00,0x27,0x20,0x16,0x5c,0x3a,0xdf,
   0xea,0xde,0xe4,0xa1,0x00,0x25,0xea,0x22,0x13,0x5a,0x27,0x12,0x08,0x3c,0xa6,0x00,
   0xde,0xe6,0x08,0xdf,0xe6,0xa1,0x00,0x38,0x22,0xd7,0x27,0xed,0x0d,0x39,0xd6,0xe8,
   0x86,0xc0,0x0c,0x39,0x7f,0x00,0xb0,0x39,0x7f,0x00,0xb6,0xc5,0x04,0x27,0x03,0x7f,
   0x00,0xb1,0xce,0x00,0xb5,0xa6,0x00,0x84,0xfc,0xc4,0x03,0x1b,0x8a,0x04,0xa7,0x00,
   0x85,0x08,0x26,0x25,0x62,0x08,0x00,0x07,0xd6,0x7c,0xfd,0x00,0xbc,0x0f,0x5f,0xd7,
   0x7c,0xcc,0x05,0x0e,0xfd,0x20,0x54,0xcc,0x05,0x63,0xfd,0x20,0x52,0xcc,0x05,0x1b,
   0xfd,0x20,0x4c,0xcc,0x03,0xc1,0xfd,0x20,0x48,0x36,0x6b,0x10,0x00,0x26,0x4d,0x3c,
   0x8d,0x52,0x38,0x25,0x48,0x7b,0x01,0x15,0x26,0x46,0x0f,0x72,0x40,0x17,0x72,0x08,
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
  };
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
int main()
{
  //DEBUG_STOP;
  char line[80];

#if FF_FIRST_BYTES
  for(int k=0; k< 100; k++)
    {
      pak_memory[k] = 0xff;
    }
#endif

  stdio_init_all();

  printf("\nPAK gadget\n");
  
#if TEST_STDIO
  {
    int count;
    while (true)
      {
	count++;
      
	if( (count % 1000000) == 0 )
	  {
	    sprintf(line, "\nRP2040: %d", count);
	    printf(line);
	  }
      }
  }
#endif
  
  printf("\nSetting GPIOs...");

  // No SD card on top slot
#if 0  
  gpio_init(22);
  
  // Select the SD card
  gpio_put(22, 0);
  gpio_set_dir(22, GPIO_OUT);
  gpio_put(22, 0);

#endif
  
  // Set up directions for the control lines
  gpio_init(SLOT_SS_PIN);
  gpio_init(SLOT_SCLK_PIN);
  gpio_init(SLOT_SMR_PIN);
  gpio_init(SLOT_SOE_PIN);
  gpio_init(SLOT_SPGM_PIN);

  for(int i=0; i<8; i++)
    {
      gpio_init(data_gpio[i]);
    }
  
  gpio_set_dir(SLOT_SS_PIN, GPIO_IN);
  gpio_set_dir(SLOT_SCLK_PIN, GPIO_IN);
  gpio_set_dir(SLOT_SMR_PIN, GPIO_IN);
  gpio_set_dir(SLOT_SOE_PIN, GPIO_IN);
  gpio_set_dir(SLOT_SPGM_PIN, GPIO_IN);

  // Drive data bus towards us
  gpio_init(LS_DIR_PIN);
  gpio_put(LS_DIR_PIN, 1);

  // LS_DIR is an output
  gpio_set_dir(LS_DIR_PIN, GPIO_OUT);
  set_bus_inputs();

  // Take both latch clocks high
  gpio_init(IP_CLK_PIN);
  gpio_set_dir(IP_CLK_PIN, GPIO_OUT);
  gpio_put(IP_CLK_PIN, 1);
  
  gpio_init(OP_CLK_PIN);
  gpio_set_dir(OP_CLK_PIN, GPIO_OUT);
  gpio_put(OP_CLK_PIN, 0);
  
  // Set up IO port
  gpio_set_function(IO7_PIN, GPIO_FUNC_NULL);
  
  for(int i=0; i<8; i++)
    {
      gpio_init(ioport_gpio[i]);
    }

  set_ioport_outputs();

  int ioport_value = 0;
  set_ioport(ioport_value);
  
  // test ioport
#if TEST_IOPORT
  while(1)
    {
      set_ioport(ioport_value);
      loop_delay(100000);
      ioport_value += (1<<5);
    }
#endif
  
#if USE_INTERRUPTS
  gpio_set_irq_enabled_with_callback(SLOT_SS_PIN,   GPIO_IRQ_EDGE_RISE | GPIO_IRQ_EDGE_FALL, true, &gpio_callback);
  gpio_set_irq_enabled_with_callback(SLOT_SCLK_PIN, GPIO_IRQ_EDGE_RISE | GPIO_IRQ_EDGE_FALL, true, &gpio_callback);
  gpio_set_irq_enabled_with_callback(SLOT_SMR_PIN,  GPIO_IRQ_EDGE_RISE | GPIO_IRQ_EDGE_FALL, true, &gpio_callback);
  gpio_set_irq_enabled_with_callback(SLOT_SOE_PIN,  GPIO_IRQ_EDGE_RISE | GPIO_IRQ_EDGE_FALL, true, &gpio_callback);
  gpio_set_irq_enabled_with_callback(SLOT_SPGM_PIN, GPIO_IRQ_EDGE_RISE | GPIO_IRQ_EDGE_FALL, true, &gpio_callback);
#endif

#if 0
  printf("\nInitialising Sd card driver...");
  
  // Initialise SD card driver
  sd_init_driver();

  printf("\nSetting up buttons...");
  
  // Set up button gpios
  for(int i=0; i<NUM_BUTTONS; i++)
    {
      gpio_init(but_pins[i]);
      gpio_set_dir(but_pins[i], GPIO_IN);

#if PICOPAK      
      // Set pull ups for buttons
      gpio_set_pulls(but_pins[i], 1, 0);
#endif
    }

#if 0  
  // SW3 is special for now
  gpio_init(SW3_PIN);
  gpio_set_dir(SW3_PIN, GPIO_IN);
#endif
  
#if PICOPAK      
  // Set pull ups for buttons
  gpio_set_pulls(SW3_PIN, 1, 0);
#endif
#endif
  
  printf("\nSetting up OLED...");
    
  // Set up OLED display
  i2c_init(&i2c_bus_0);
    
  oled_setup(&oled0);

#if 0  
  // Set up the OLED menu
  
  current_menu = &(home_menu[0]);
  last_menu = &(home_menu[0]);
  the_home_menu = last_menu;

  to_home_menu(NULL);

  init_buttons();
#endif
  
  int count = 0;

#if MULTICORE_POLL
  // Start the address handling on the other core
  multicore_launch_core1(handle_address);
#endif

  // Main loop that updates OLED display if using interrupts
#if USE_INTERRUPTS
  for (;;)
    {
#if 1
      // Monitor the SS line and count how many falling edges there are
      
      sprintf(line, "%d %d %d %d        ", count, ss_count, ss_address, soe_state);
      oled_set_xy(&oled0, 0, 21);
      oled_display_string(&oled0, line);
      
      count++;
#endif

    }
#endif  

#if USE_POLLING
  // Use a polling loop for minimum latency

#if NO_INTERRUPTS_WHILE_POLLING  
  // Turn off timer interrupts
  irq_set_mask_enabled(0xf, false);
#endif

#if 0
  // Read config file into memory buffer
  // That will tell us which file to load
  process_config_file(&oled0);
#endif

  // Try writing to latch.
  // Psion MUST NOT be attached

#if 0
  for(int i=0; i<8; i++)
    {
      gpio_set_dir(data_gpio[i], GPIO_OUT);
    }
  
  set_bus_outputs();

  int countx = 0;
  
  while(1)
    {
      set_data_bus(countx++);
      sleep_us(100000L);
      gpio_put(OP_CLK_PIN, 1);
      gpio_put(OP_CLK_PIN, 1);
      gpio_put(OP_CLK_PIN, 1);
      gpio_put(OP_CLK_PIN, 1);
      gpio_put(OP_CLK_PIN, 1);
      gpio_put(OP_CLK_PIN, 0);
      
    }
#endif
  
  while(1)
    {
      int last_ss;
      int last_sclk;
      int last_soe;
      int last_smr;
      int last_spgm;
  
      last_ss     = gpio_get(SLOT_SS_PIN);
      last_sclk   = gpio_get(SLOT_SCLK_PIN);
      last_soe    = gpio_get(SLOT_SOE_PIN);
      last_smr    = gpio_get(SLOT_SMR_PIN);
      last_spgm   = gpio_get(SLOT_SPGM_PIN);
      
      int ss;
      int sclk;
      int soe;
      int smr;
      int spgm;

      printf("\nTop Slot Gadget\n");
      stdio_flush();
      
      
      // Overall loop, which contains the polling loop and the menu loop
      oled_clear_display(&oled0);
      
      oled_set_xy(&oled0, 0,0);
      oled_display_string(&oled0, "Top Slot Gadget");
      
#if USE_INTERRUPTS
      oled_set_xy(&oled0, 0,14);
      oled_display_string(&oled0, "Interrupts");
#endif

      
#if 0      
#if USE_POLLING
      oled_set_xy(&oled0, 0,14);
      oled_display_string(&oled0, "Polling");
#endif
#endif

#if 0      
      // Mount and unmount the SD card to set the sd_ok_flag up
      mount_sd();
      unmount_sd();

      
      oled_set_xy(&oled0, 0,21);
      if( sd_ok_flag )
	{
	  oled_display_string(&oled0, "SD card OK");
	}
      else
	{
	  oled_display_string(&oled0, "SD card NOT OK");
	}

      oled_set_xy(&oled0, 0,28);
#if PICOPAK
      oled_display_string(&oled0, "Left Button:Menu");
#else      
      oled_display_string(&oled0, "Bottom Button:Menu");
#endif
      
      oled_set_xy(&oled0, 0,35);
      //oled_display_string(&oled0, current_file);
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

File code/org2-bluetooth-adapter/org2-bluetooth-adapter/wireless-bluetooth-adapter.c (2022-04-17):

////////////////////////////////////////////////////////////////////////////////
//
//
#include <ctype.h>
#include <stdio.h>
#include <string.h>
#include <stdlib.h>
#include "pico/stdlib.h"
//#include "hardware/i2c.h"
#include "hardware/pio.h"
//#include "hardware/clocks.h"
#include "hardware/uart.h"
#include "hardware/irq.h"

#include "org2-bluetooth-adapter.h"
#include "match.h"
#include "wireless-bluetooth-adapter.h"
#include "org2-bluetooth-adapter.pio.h"

void start_task(char *label);
void remove_string(char *str);
void remove_n(int n);

void rfn_null(void);
void rfn_send_done(void);
void rfn_set_link_up(void);
  
int ifm_null(int i);
void ifn_ignore(int i);
int ifm_ipd(int i);
int ifm_cipsend(int i);
int ifm_recv(int i);

void ifn_next_is_ok(int i);
void ifn_check_ok(int i);
void ifn_ready(int i);
void ifn_ipd(int i);
void ifn2_ipd(void);
void ifn_ciprecvdata(int i);
void ifn_null(int i);
void ifn_cipsend(int i);
void ifn_recv(int i);
void ifn_closed(int i);
void ifn_busy(int i);
void ifn_connect(int i);
void ifn_disconnect(int i);
void ifn_btdata(int i);
void ifn2_btdata(void);
void ifn_startdisc(int i);
void ifn_startdisc2(int i);

void ufn_index(void);
void ufn_memory_0(void);
void ufn_memory_at(void);
void ufn_memory_write(void);
void ufn_ram(void);
void ufn_eeprom_write(void);
void ufn_eeprom_read(void);

void btfn_hello(void);
void btfn_mem_rd(void);
void btfn_eeprom_rd(void);
void btfn_eeprom_wr(void);
void btfn_mem_wr(void);
void btfn_processor_status(void);
void btfn_display(void);
void btfn_key(void);

void push_key(int keycode, int offset);
void process_bt_term(BYTE *byte_buffer, int num);

////////////////////////////////////////////////////////////////////////////////
//
// Discovered devices


int bt_device_i = 0;
BT_DEVICE bt_device[NUM_BT_DEVICES];

#define BT_ADDR_SIZE 6

// The bluetooth device we will connect to when in master mode.
char *bt_connect_name = "Topcon_Default";
int bt_connect_addr[BT_ADDR_SIZE];

////////////////////////////////////////////////////////////////////////////////

int w_task_index = 0;
int w_task_running = 0;
uint64_t w_task_delay_end = 0;
int w_task_delaying = 0;

char cmd[200];
char delay_text[20];
char output_text[2000];
int output_text_len = 0;

// Temporary result text buffer
char temp_output_buffer[2000];

#define INPUT_TEXT_SIZE  2000

char input_text[INPUT_TEXT_SIZE+1];
int input_text_len = 0;

char input_temp[2000];
char input_data[2000];
char uri[200];

int n_scanned, chan, numchars, num_scanned;
int v1,v2;

// Current connection number
int connection = 0;

int tasks_run = 0;

typedef void (*BYTE_CONT_FN)(void);
typedef void (*ON_OK_FN)(void);

char byte_buffer[2000];
int byte_buffer_index;
int collecting_bytes = 0;
BYTE_CONT_FN when_done_fn;
int bytes_left_to_collect = 0;
int num_bytes_collected = 0;
int sending_bt_data = 0;

//------------------------------------------------------------------------------
//
// Bluetooth input buffer
//

// Switch that determines where BT is going and coming from
// For the bluetooth adapter we use the comms link mode
int bluetooth_mode = BT_MODE_COMMS_LINK;

#define BT_CL_BUFFER_SIZE  1000

int bt_cl_in = 0;
int bt_cl_out = 0;

BYTE bt_cl_buffer[BT_CL_BUFFER_SIZE];

// Bluetooth output buffer (sending over BT)
int cl_bt_in = 0;
int cl_bt_out = 0;

BYTE cl_bt_buffer[CL_BT_BUFFER_SIZE];
int pending_tx = 0;

////////////////////////////////////////////////////////////////////////////////

#define WIFI_UART_PIO 1

#define UART_ID uart1 //uart0
#define BAUD_RATE 115200
#define DATA_BITS 8
#define STOP_BITS 1
#define PARITY    UART_PARITY_NONE

// We are using pins 0 and 1, but see the GPIO function select table in the
// datasheet for information on which other pins can be used.
#define UART_TX_PIN 4 //0
#define UART_RX_PIN 5 //1


#if UART_INTERRUPTS

#define INTERRUPT_TEXT_SIZE 5000

volatile char interrupt_text[INTERRUPT_TEXT_SIZE+1];
volatile  int irq_text_out_ptr = 0;
volatile  int irq_text_in_ptr = 0;

// RX interrupt handler
volatile int irq_count = 0;
volatile int irq_no_char = 0;
volatile int irq_after = 0;
volatile int char_in_loop = 0;

void on_uart_rx()
{
  int np = 0;
  
  irq_count++;
  
  if( !uart_is_readable(UART_ID) )
    {
      irq_no_char++;
    }
  
  while (uart_is_readable(UART_ID))
    {
      uint8_t ch = uart_getc(UART_ID);

      if( ch != '\0' )
	{
	  interrupt_text[irq_text_in_ptr] = ch;
	  np = irq_text_in_ptr;
	  np++;
	  irq_text_in_ptr = (np % INTERRUPT_TEXT_SIZE);
	}
    }

  if( uart_is_readable(UART_ID) )
    {
      irq_after++;
    }

}

#endif

#if WIFI_UART_PIO
#endif

////////////////////////////////////////////////////////////////////////////////
//
// Functions to send and receive data from and to the Wireless module
//
////////////////////////////////////////////////////////////////////////////////

// Send text to the wifi module.
// We have to buffer the text and send it as the PIO FIFO becomes free

// This function puts something in the buffer
void w_uart_puts(char *cmd)
{
  while( (*cmd) != '\0' )
    {
      w_data_out[data_wtx_in_idx] = *(cmd++);
      data_wtx_in_idx = (data_wtx_in_idx + 1) % DATA_WTX_LEN;
    }
}

// This function sends the buffer contents if it can
void w_uart_tasks(void)
{
  // 
  if( data_wtx_out_idx != data_wtx_in_idx )
    {
      if( !pio_sm_is_tx_fifo_full(wtx_pio, wtx_sm) )
	{
	  uart_wtx_program_putc(wtx_pio, wtx_sm, w_data_out[data_wtx_out_idx]);
	  data_wtx_out_idx = (data_wtx_out_idx+1) % DATA_WTX_LEN;
	}
    }
}

////////////////////////////////////////////////////////////////////////////////
//
// Initialise the wireless module code
//
////////////////////////////////////////////////////////////////////////////////

void wireless_init(void)
{

#if WIFI_UART_PIO


#else
  sleep_us(1000000);  
  gpio_set_function(UART_TX_PIN, GPIO_FUNC_UART);
  gpio_set_function(UART_RX_PIN, GPIO_FUNC_UART);

  uart_init(UART_ID, BAUD_RATE);
  uart_set_hw_flow(UART_ID, false, false);
  uart_set_fifo_enabled(UART_ID, false);
#endif
  
#if UART_INTERRUPTS
  // Set up a RX interrupt
  // We need to set up the handler first
  // Select correct interrupt for the UART we are using
  int UART_IRQ = UART_ID == uart0 ? UART0_IRQ : UART1_IRQ;
  
  // And set up and enable the interrupt handlers
  irq_set_exclusive_handler(UART_IRQ, on_uart_rx);
  irq_set_enabled(UART_IRQ, true);
  
  // Now enable the UART to send interrupts - RX only
  uart_set_irq_enables(UART_ID, true, false);
  
#endif
    
  //  gpio_put(7, 1);
  //gpio_set_dir(7, GPIO_OUT);
  
  printf("\nOrganiser 2 Bluetooth Adatper\n");
  stdio_flush();

  // Turn power to the WROOM off for a while
  gpio_put(WROOM_ON_PIN, 0);
  for(volatile int i=0; i<100000;i++)
    {
      volatile j = i+i;
    }
  
  //sleep_ms(100);
  gpio_put(WROOM_ON_PIN, 1);

  input_text[0] = '\0';
  input_text_len = 0;
}

volatile int setup = 0;
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

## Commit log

2021-12-29 Initial check in
    [a.sch, bt.sch, file613E6C74.sch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]
2021-12-30 V1_0 PCB sent off
    [Power.sch, file61D041BF.sch, pak_breakout.kicad_pcb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]
2022-01-02 Changed circuit to new power arrangement
    [Power.sch, file61D041BF.sch, psion-org2-bluetooth-adapter.kicad_pcb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]
2022-02-05 Added code
    [Power.sch, a.sch, bt.sch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]
2022-02-10 V2.0 PCB, new charger IC, USB power option
    [Power.sch]
2022-02-10 Merged erroneous changes to V1.0 archive started
    [Power.sch, a1.sch, b1.sch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]
2022-02-14 V2.0 sent off for fab. New charger IC with more solderable footprint, plus other fixes
    [Power.sch, file61D041BF.sch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]
2022-02-21 Removing OLED accesses prevents some errors. RECEIVE and TRANSMIT still give errors
    [org2-bluetooth-adapter.c, org2-bluetooth-adapter.h, wireless-bluetooth-adapter.c]
2022-03-05 Updates that stop the code from working. ROm read is problematic, not sure how demo worked.
    [psion-org2-bluetooth-adapter.sch]
2022-03-05 Moved wireless work to core1, ROM address handling in core0 loop, works better, maybe
2022-03-11 Updates, psion link not working
    [Power.sch, psion-org2-bluetooth-adapter.kicad_pcb]
2022-03-12 These changes are a bluetooth adapter that doesn't use interrupts as that messes up the ROM load. The PIOs are used for two UARTS and no interrupts and not blocking. Two way comms sems to work The wi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
    [psion-org2-bluetooth-adapter.sch]
2022-03-13 Change added that delays RX from Psion until bluetooth is set up. This was causing a lock up when starting the code up. Still gives error on exit from TERM or TRANSMIT. Also gets into a state which s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
    [org2-bluetooth-adapter.c, org2-bluetooth-adapter.h, wireless-bluetooth-adapter.c]
2022-03-15 Master mode working now. Still some problems with TRANSMIT menu option. Two way comms between two Psions using TERM menu option works
    [org2-bluetooth-adapter.c, org2-bluetooth-adapter.h, wireless-bluetooth-adapter.c]
2022-04-12 This is a version of code that works with the BT between a Gemini and the Psion in slave mode. Master mode shouldn't be a problem, but hasn't been tested. This is a base version of code that can be u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
    [org2-bluetooth-adapter.c, org2-bluetooth-adapter.h, wireless-bluetooth-adapter.c]
2022-04-17 This code workjs, except for:
    1. Garbage when entering TERM mode appears on the BT device.
    2. Garbage also appears on BT devie before a programmed LPRINT statement.
    3. Garbage appears on a programmed read as well.
    4. Device read error after programmed read.
    [org2-bluetooth-adapter.c]
2022-04-17 Problem with gargabe on BT end when selecting the hardware seems to be fixed. It was due, I think, to the RX line always being active. This meant that transitions were seen when the data bus was bein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
    problems
    We still see DEVICE READ ERROR when running a programmed RX (but not in TERM mode) and
    data is sent to the BT adapter. maybe when more characters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
    [org2-bluetooth-adapter.c]
